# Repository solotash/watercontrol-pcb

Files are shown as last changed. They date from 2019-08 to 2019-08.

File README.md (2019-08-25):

# WaterControl - PCB

A simple PCB for controlling two small 12V pumps and two capacitive soil moisture sensors with an esp-12f, powered by a usual 12V power supply (eg for external HDD drives).

If you have any questions, open an issue, Ill answer gladly! 

For gerber files, look at the [release(s)](https://github.com/mqus/watercontrol-pcb/releases)

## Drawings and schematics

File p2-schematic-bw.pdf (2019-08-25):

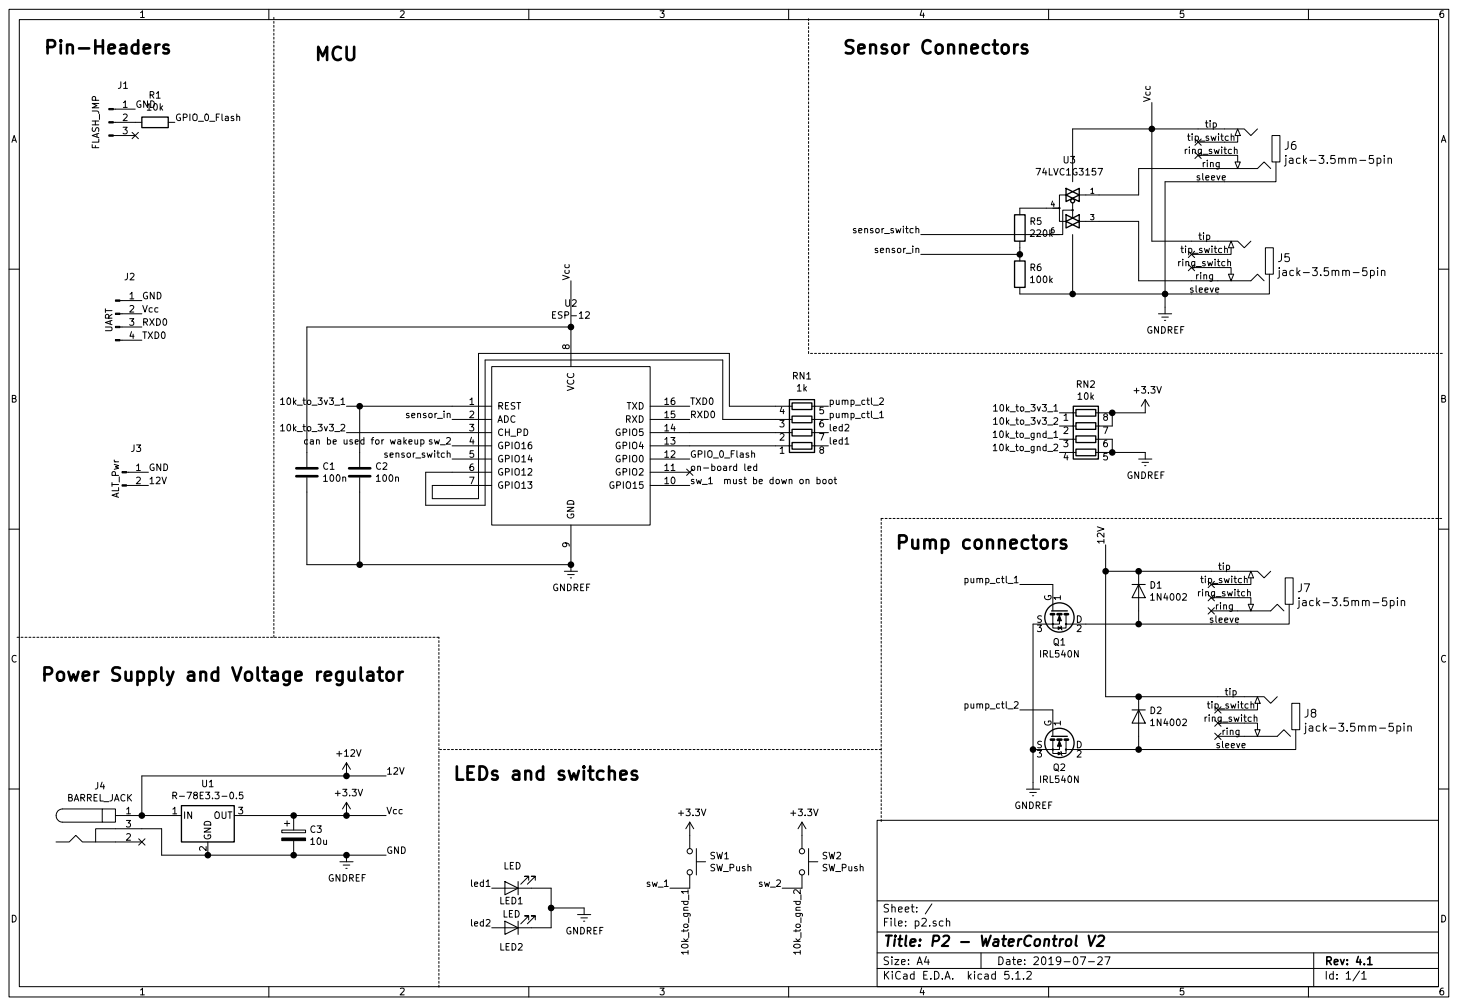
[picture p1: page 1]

can be used for wakeup

on-board led must be down on boot

Power Supply and Voltage regulator

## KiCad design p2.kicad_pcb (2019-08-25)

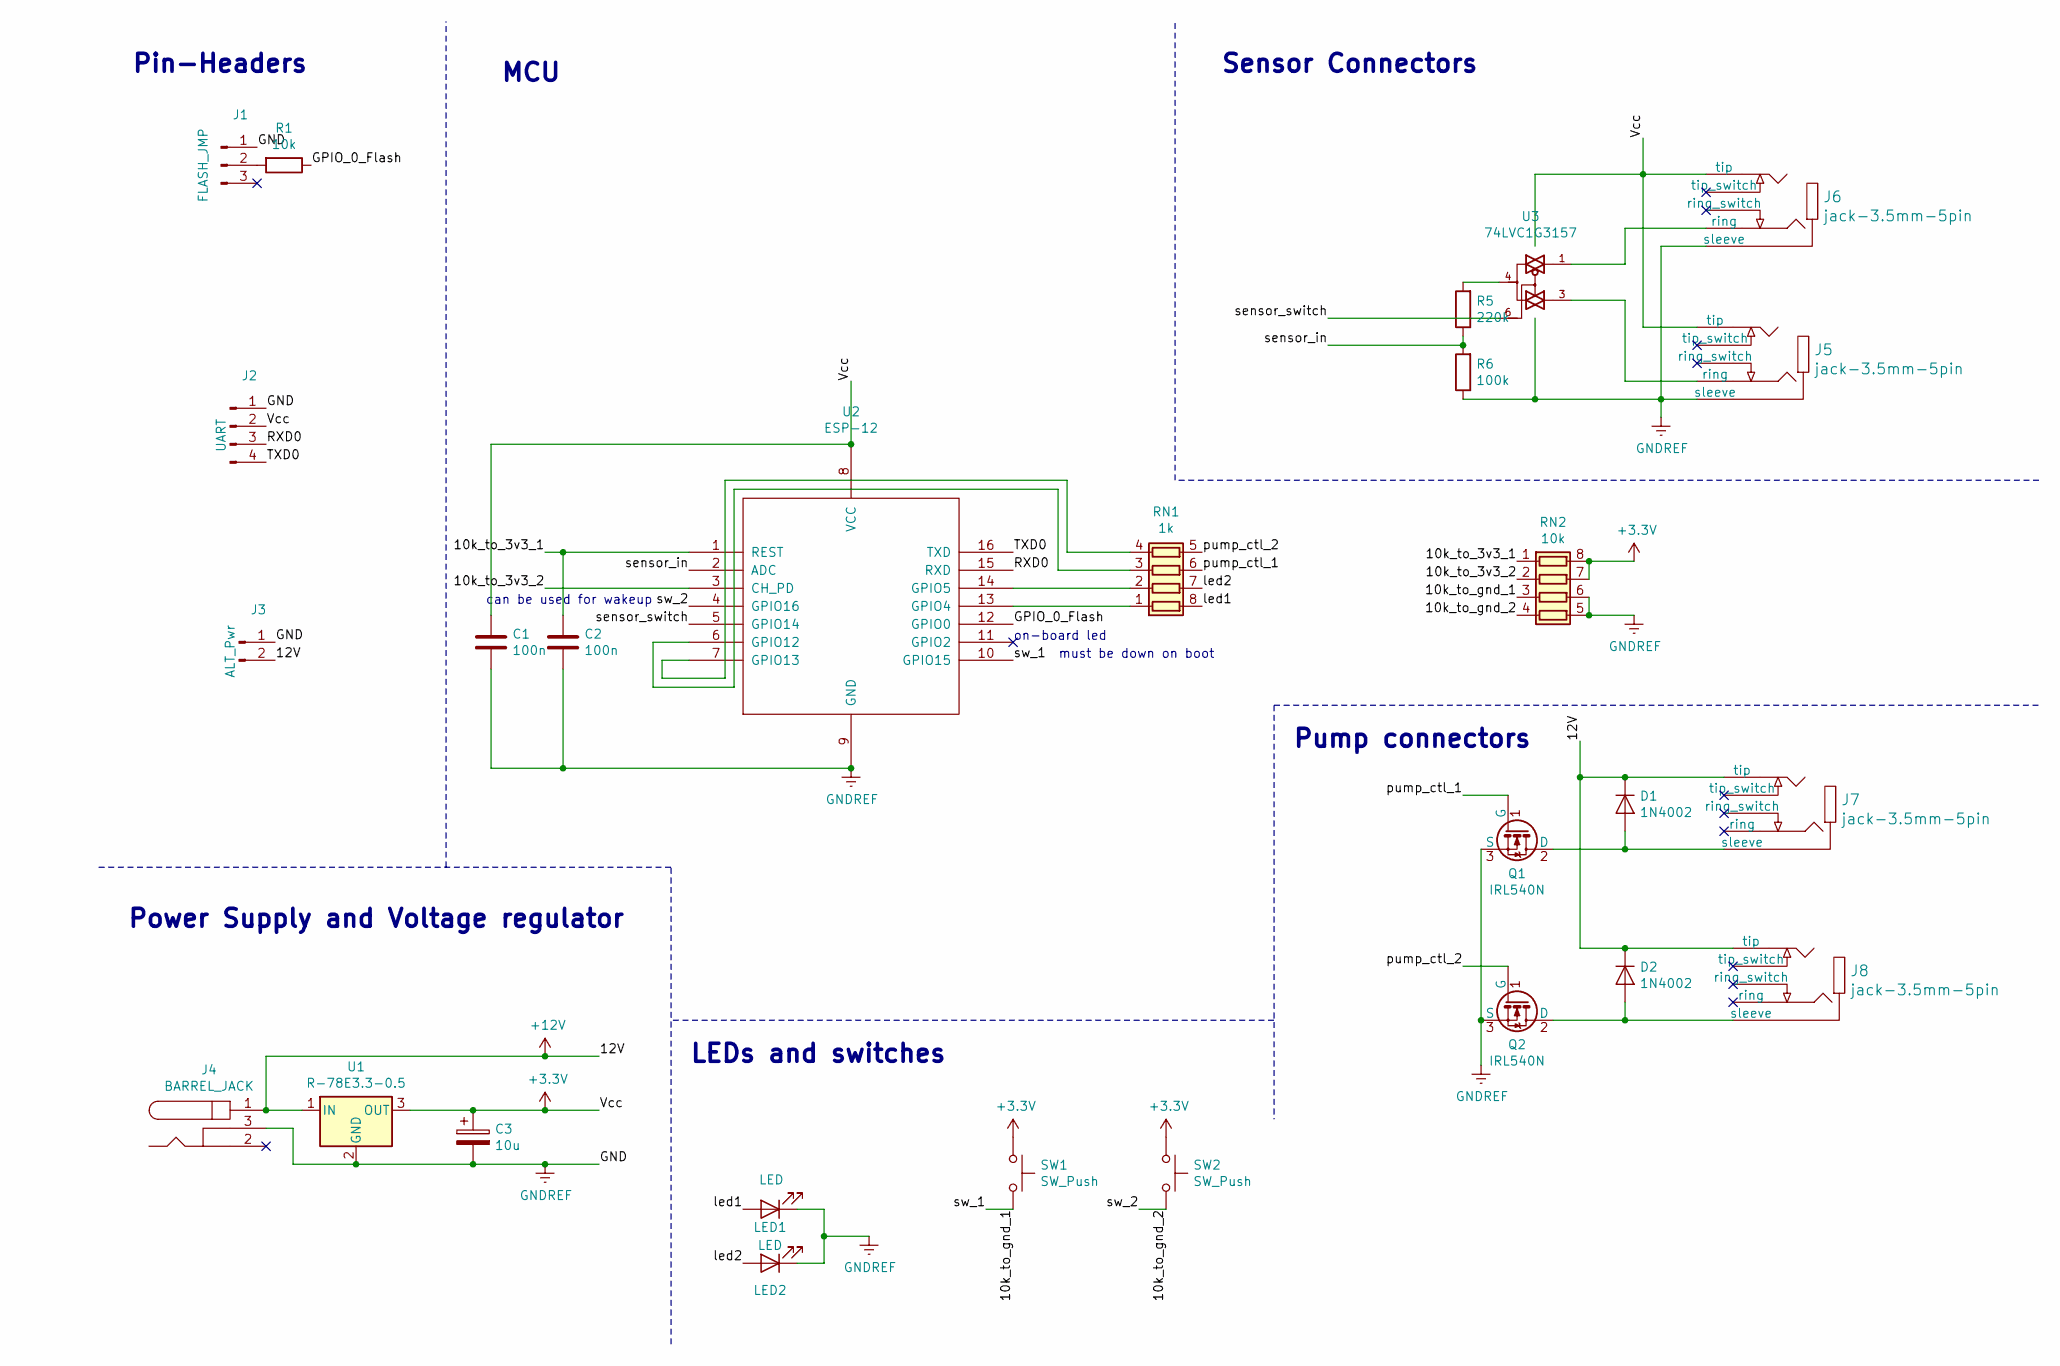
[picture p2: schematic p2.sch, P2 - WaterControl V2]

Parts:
C1, C2: 100n; C_Disc_D5.0mm_W2.5mm_P5.00mm
C3: 10u; CP_Radial_Tantal_D5.0mm_P2.50mm
D1, D2: 1N4002; D_A-405_P10.16mm_Horizontal
J1: FLASH_JMP; PinHeader_2.54mm_1x3_short
J2: UART; PinHeader_1x04_P2.54mm_Vertical
J3: ALT_Pwr; PinHeader_1x02_P2.54mm_Vertical
J4: BARREL_JACK; Barrel_Jack_5.5_2.1mm
J5, J6, J7, J8: jack-3.5mm-5pin; 3.5mm_5pin_jack
LED1, LED2: LED; LED_D3.0mm_Horizontal_O1.27mm_Z2.0mm_Clear
Q1: IRL540N; TO-220-3_Horizontal_TabUp
Q2: IRL540N; TO-220-3_Horizontal_TabDown
R1: 10k; R_Axial_DIN0207_L6.3mm_D2.5mm_P7.62mm_Horizontal
R5: 220k; R_Axial_DIN0207_L6.3mm_D2.5mm_P7.62mm_Horizontal
R6: 100k; R_Axial_DIN0207_L6.3mm_D2.5mm_P7.62mm_Horizontal
RN1: 1k; ResistorArrayx4-27185436
RN2: 10k; ResistorArrayx4-18726345
SW1, SW2: SW_Push; SW_Tactile_SPST_Angled_PTS645Vx58-2LFS
U1: R-78E3.3-0.5; DCDC-Conv_Recom_R-78Exx-0.5
U2: ESP-12
U3: 74LVC1G3157; SOT-363_SC-70-6_Handsoldering

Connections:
+3V3: C1.1, C3.1, J2.2, J5.2 (tip), J6.2 (tip), RN2.7 (R2.2), RN2.8 (R1.2), SW1.1, SW2.1, U1.3 (OUT), U2.8 (VCC), U3.5 (VCC)
+12V: D1.1 (K), D2.1 (K), J3.2, J4.1, J7.2 (tip), J8.2 (tip), U1.1 (IN)
/10k_to_3v3_1: C2.1, RN2.1 (R1.1), U2.1 (REST)
/10k_to_3v3_2: RN2.2 (R2.1), U2.3 (CH_PD)
/10k_to_gnd_1: RN2.3 (R3.1), SW1.2, U2.10 (GPIO15)
/10k_to_gnd_2: RN2.4 (R4.1), SW2.2, U2.4 (GPIO16)
/GPIO_0_Flash: R1.1, U2.12 (GPIO0)
/RXD0: J2.3, U2.15 (RXD)
/TXD0: J2.4, U2.16 (TXD)
/led1: LED1.2 (A), RN1.8 (R1.2)
/led2: LED2.2 (A), RN1.7 (R2.2)
/pump_ctl_1: Q1.1 (G), RN1.6 (R3.2)
/pump_ctl_2: Q2.1 (G), RN1.5 (R4.2)
/sensor_in: R5.1, R6.2, U2.2 (ADC)
/sensor_switch: U2.5 (GPIO14), U3.6
GND: C1.2, C2.2, C3.2, J1.1, J2.1, J3.1, J4.3, J5.1 (sleeve), J6.1 (sleeve), LED1.1 (K), LED2.1 (K), Q1.3 (S), Q2.3 (S), R6.1, RN2.5 (R4.2), RN2.6 (R3.2), U1.2 (GND), U2.9 (GND), U3.2 (GND)
unnamed: D1.2 (A), J7.1 (sleeve), Q1.2 (D)
unnamed: D2.2 (A), J8.1 (sleeve), Q2.2 (D)
unnamed: J1.2, R1.2
unnamed: J5.3 (ring), U3.3
unnamed: J6.3 (ring), U3.1
unnamed: R5.2, U3.4
unnamed: RN1.1 (R1.1), U2.13 (GPIO4)
unnamed: RN1.2 (R2.1), U2.14 (GPIO5)
unnamed: RN1.3 (R3.1), U2.6 (GPIO12)
unnamed: RN1.4 (R4.1), U2.7 (GPIO13)

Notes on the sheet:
on-board led
must be down on boot
Pin-Headers
Power Supply and Voltage regulator
LEDs and switches
Pump connectors
Sensor Connectors
MCU
can be used for wakeup

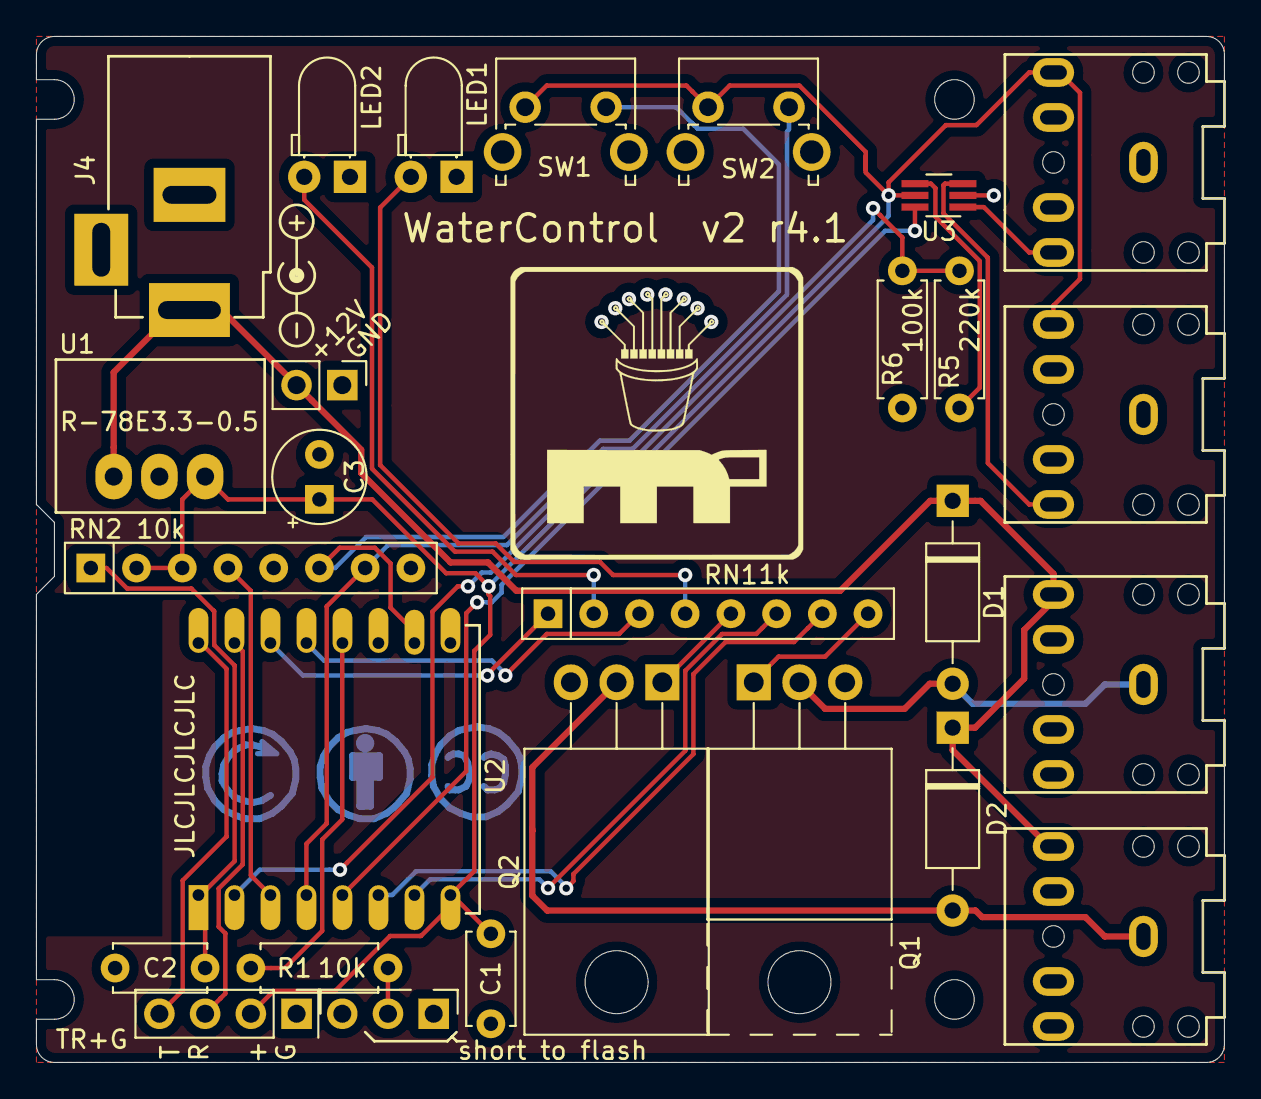
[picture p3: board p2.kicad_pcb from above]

Board: 2 copper layers, 66.0 x 57.0 mm, 27 parts (0 on the bottom side), 26 nets.

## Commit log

2017-04-24 initial commit, ref 3.3
    [p2.kicad_pcb, p2.sch]
2017-04-25 update to pcb-rev1.1
    [p2.kicad_pcb, p2.sch]
2017-04-25 update pcb to rev 1.3 (added copper pours)
    [p2.kicad_pcb]
2017-04-25 rounded corners and edge-screwholes
    [p2.kicad_pcb]
2017-04-29 now it's ready.
    [p2.kicad_pcb]
2017-06-10 current state sync
    [p2.kicad_pcb, p2.sch]
2019-08-25 rev4.1 - switched to capacitive sensors by including a multiplexer, added another switch, rotated both.
    [p2.kicad_pcb, p2.sch]
2019-08-25 ignore gerber/drill files
